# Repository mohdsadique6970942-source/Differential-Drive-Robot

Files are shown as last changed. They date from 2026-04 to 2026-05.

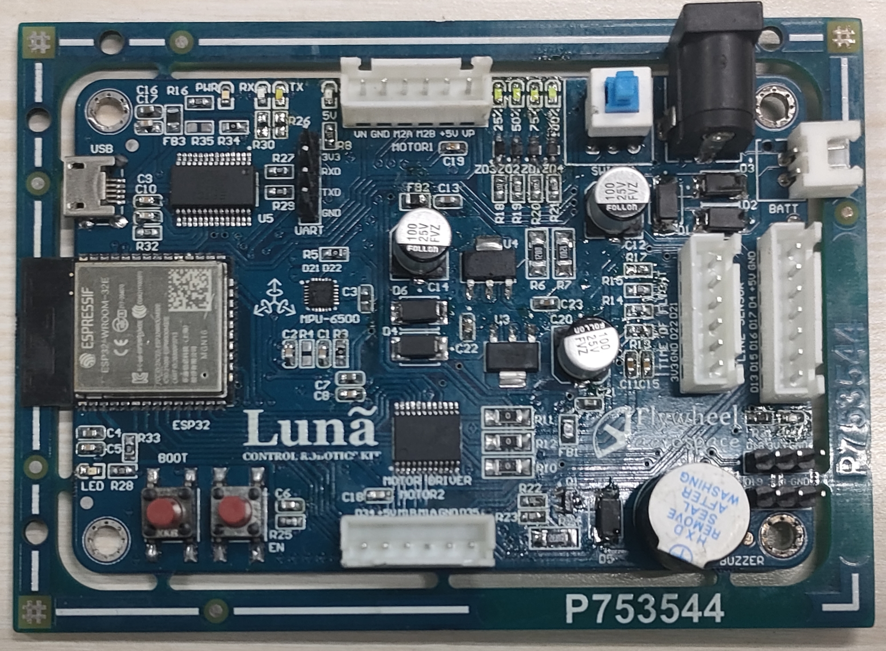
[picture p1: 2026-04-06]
PCB Design/Differrencial Drive Robot PCB Image.jpeg

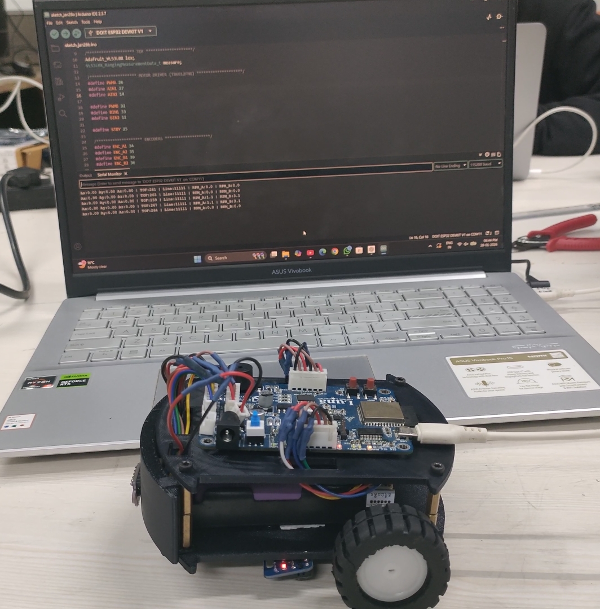
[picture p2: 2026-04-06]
Robot Images/Robot Side.jpeg

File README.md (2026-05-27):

# Differential-Drive-Robot
Differential drive mobile robot using ESP32 Dev Kit with IMU 6500, ToF, and encoder motors for precise localization, obstacle detection, and motion control. Implements sensor fusion and PID/non-PID control for accurate path tracking, also desighn a PCB for this Project with IMU, motor driver, battery charging circuit integrated in PCB, with ongoing work on mathematical modeling of the robot & development of GUI for GUI-based visualization and can get data in .csv format through GUI.

---

## 🧰 Hardware Components
- ESP32  
- IMU Sensor (MPU6500)  
- ToF Sensor (VL53L0X)  
- Two N20 DC Encoder Motors 
- Motor Driver (TB6612FNG)  
- Battery Pack (12V) 
- 3D Printed Chassis + Wheels

---

## 🔌 Pin Connections

### 🔹 Motor Driver (TB6612 / L298N Equivalent)

| Function | ESP32 Pin |
|---|---|
| PWMA (Left PWM) | 26 |
| AIN1 | 14 |
| AIN2 | 27 |
| PWMB (Right PWM) | 32 |
| BIN1 | 33 |
| BIN2 | 12 |
| STBY | 25 |

---

### 🔹 Encoder Connections

| Encoder Signal | ESP32 Pin |
|---|---|
| Left Encoder A | 34 |
| Left Encoder B | 35 |
| Right Encoder A | 39 |
| Right Encoder B | 36 |

---

### 🔹 Line Sensors (5 Array)

| Sensor | ESP32 Pin |
|---|---|
| LS1 | 4 |
| LS2 | 17 |
| LS3 | 16 |
| LS4 | 15 |
| LS5 | 13 |

---

### 🔹 IMU (MPU6050 - I2C)

| Pin | ESP32 |
|-----|---|
| VCC | 3.3V |
| GND | GND |
| SDA | 21 |
| SCL | 22 |

📌 Install Library:
- `Madgwick` (from Arduino Library Manager)

---

### 🔹 ToF Sensor (VL53L0X - I2C)

| Pin | ESP32 |
|-----|---|
| VCC | 3.3V |
| GND | GND |
| SDA | 21 |
| SCL | 22 |

📌 Install Library:
- `Adafruit_VL53L0X`

---

### 🔹 Serial Communication

| Function | Value |
|---|---|
| Baud Rate | 115200 |
| Interface | USB |

---

## 📁 Code Availability

- Individual sensor codes are available  
- Combined full system code is available
- All paths code are available 
- All codes are inside the `Robot codes` folder  
- Path execution:
  - Straight line (PID + Non-PID with jerk control)  
  - Square path (PID + Non-PID)  
  - Circular path (PID + Non-PID)
 
---

## 🖨️ 3D Print & PCB Design

- 3D printed chassis files are available in "3D print" folder
- PCB design is available in "PCB design" folder
  
---

## 🎯 Applications
- Autonomous mobile robots  
- SLAM & localization research  
- Robotics competitions  
- Smart navigation systems  

---

## 📚 Learning Outcomes
- Sensor fusion (IMU + ToF + Encoder)  
- Embedded control systems  
- PID tuning and motion control  
- Real-time robotics programming
- Mathematical Modelling

---

## 📄 License
Open-source for educational and research purposes.

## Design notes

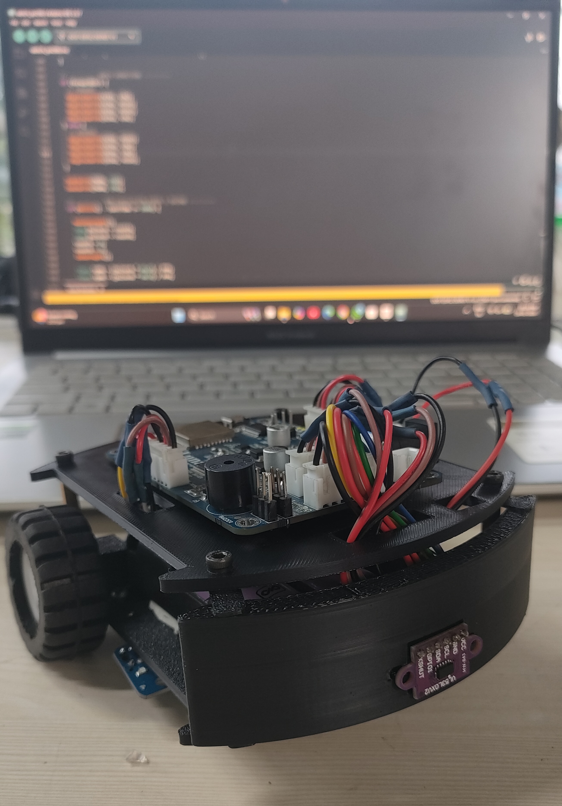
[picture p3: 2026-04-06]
Robot Images/Robot Top.jpeg

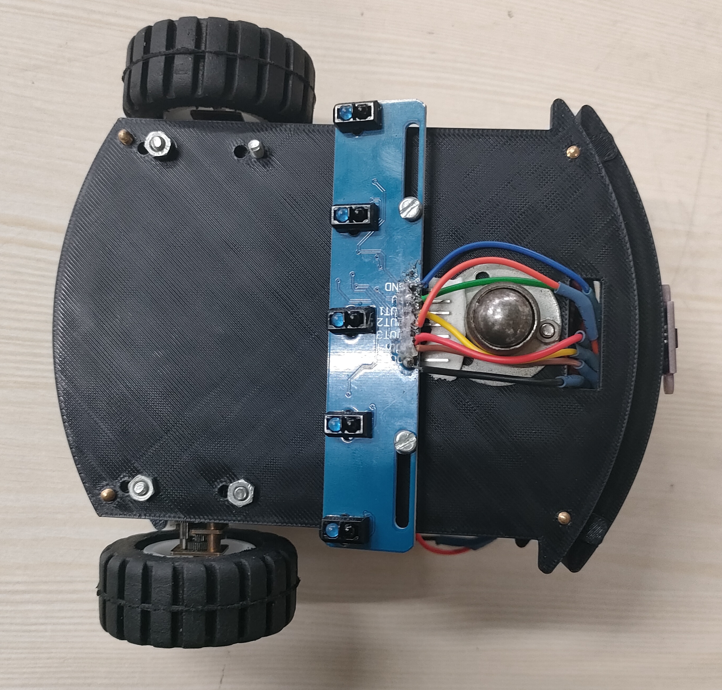
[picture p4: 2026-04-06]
Robot Images/Robot Base.jpeg

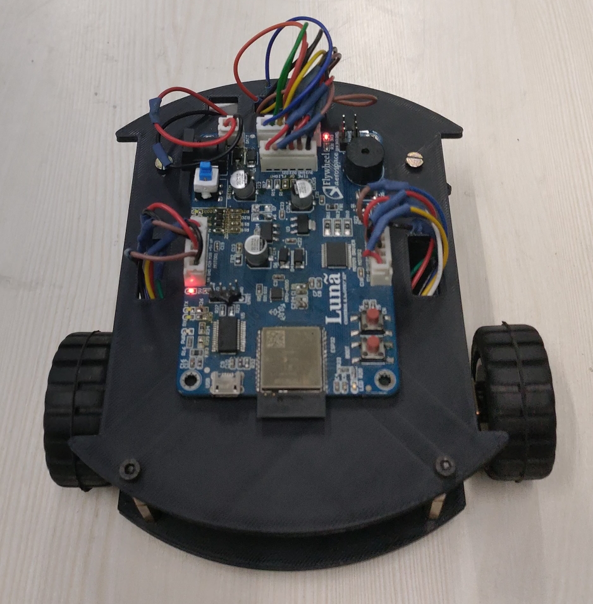
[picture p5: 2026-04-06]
Robot Images/Robot Back Top.jpeg

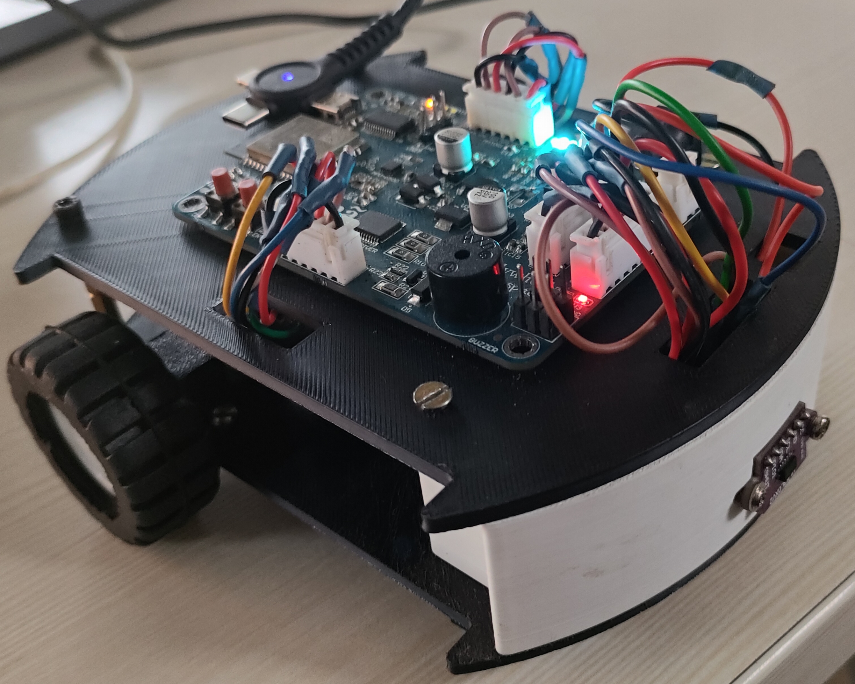
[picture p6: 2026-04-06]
Robot Images/Robot Side Top.jpeg

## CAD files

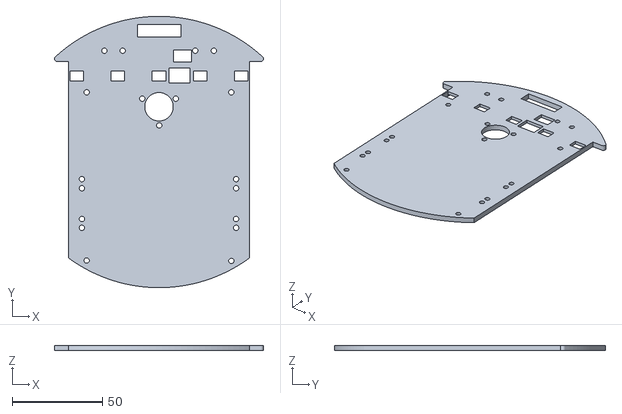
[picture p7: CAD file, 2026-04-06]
3D Prints/Robot_Base.stl
115.6 x 150.0 x 3.00

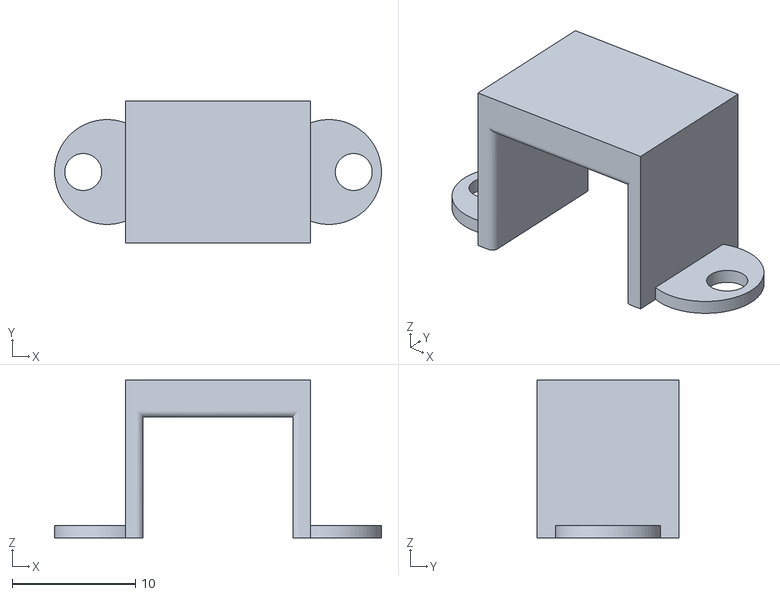
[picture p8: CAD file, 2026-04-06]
3D Prints/Robot_Motors_Clamp.stl
26.5 x 11.5 x 12.8

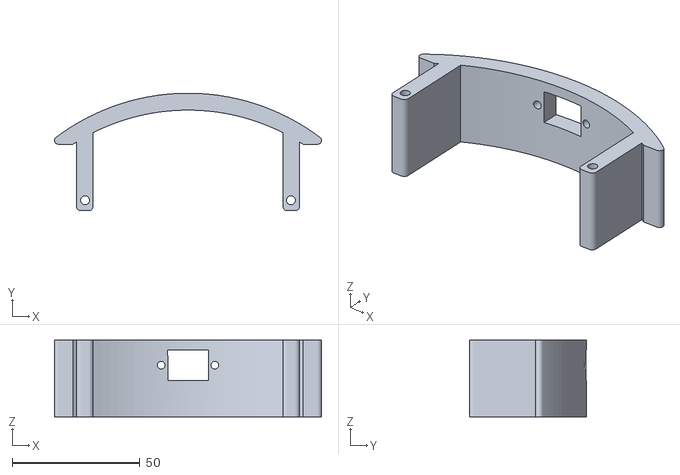
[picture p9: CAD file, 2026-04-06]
3D Prints/Robot_Front.stl
104.4 x 45.9 x 30.0

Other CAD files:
3D Prints/Robot_Top.stl

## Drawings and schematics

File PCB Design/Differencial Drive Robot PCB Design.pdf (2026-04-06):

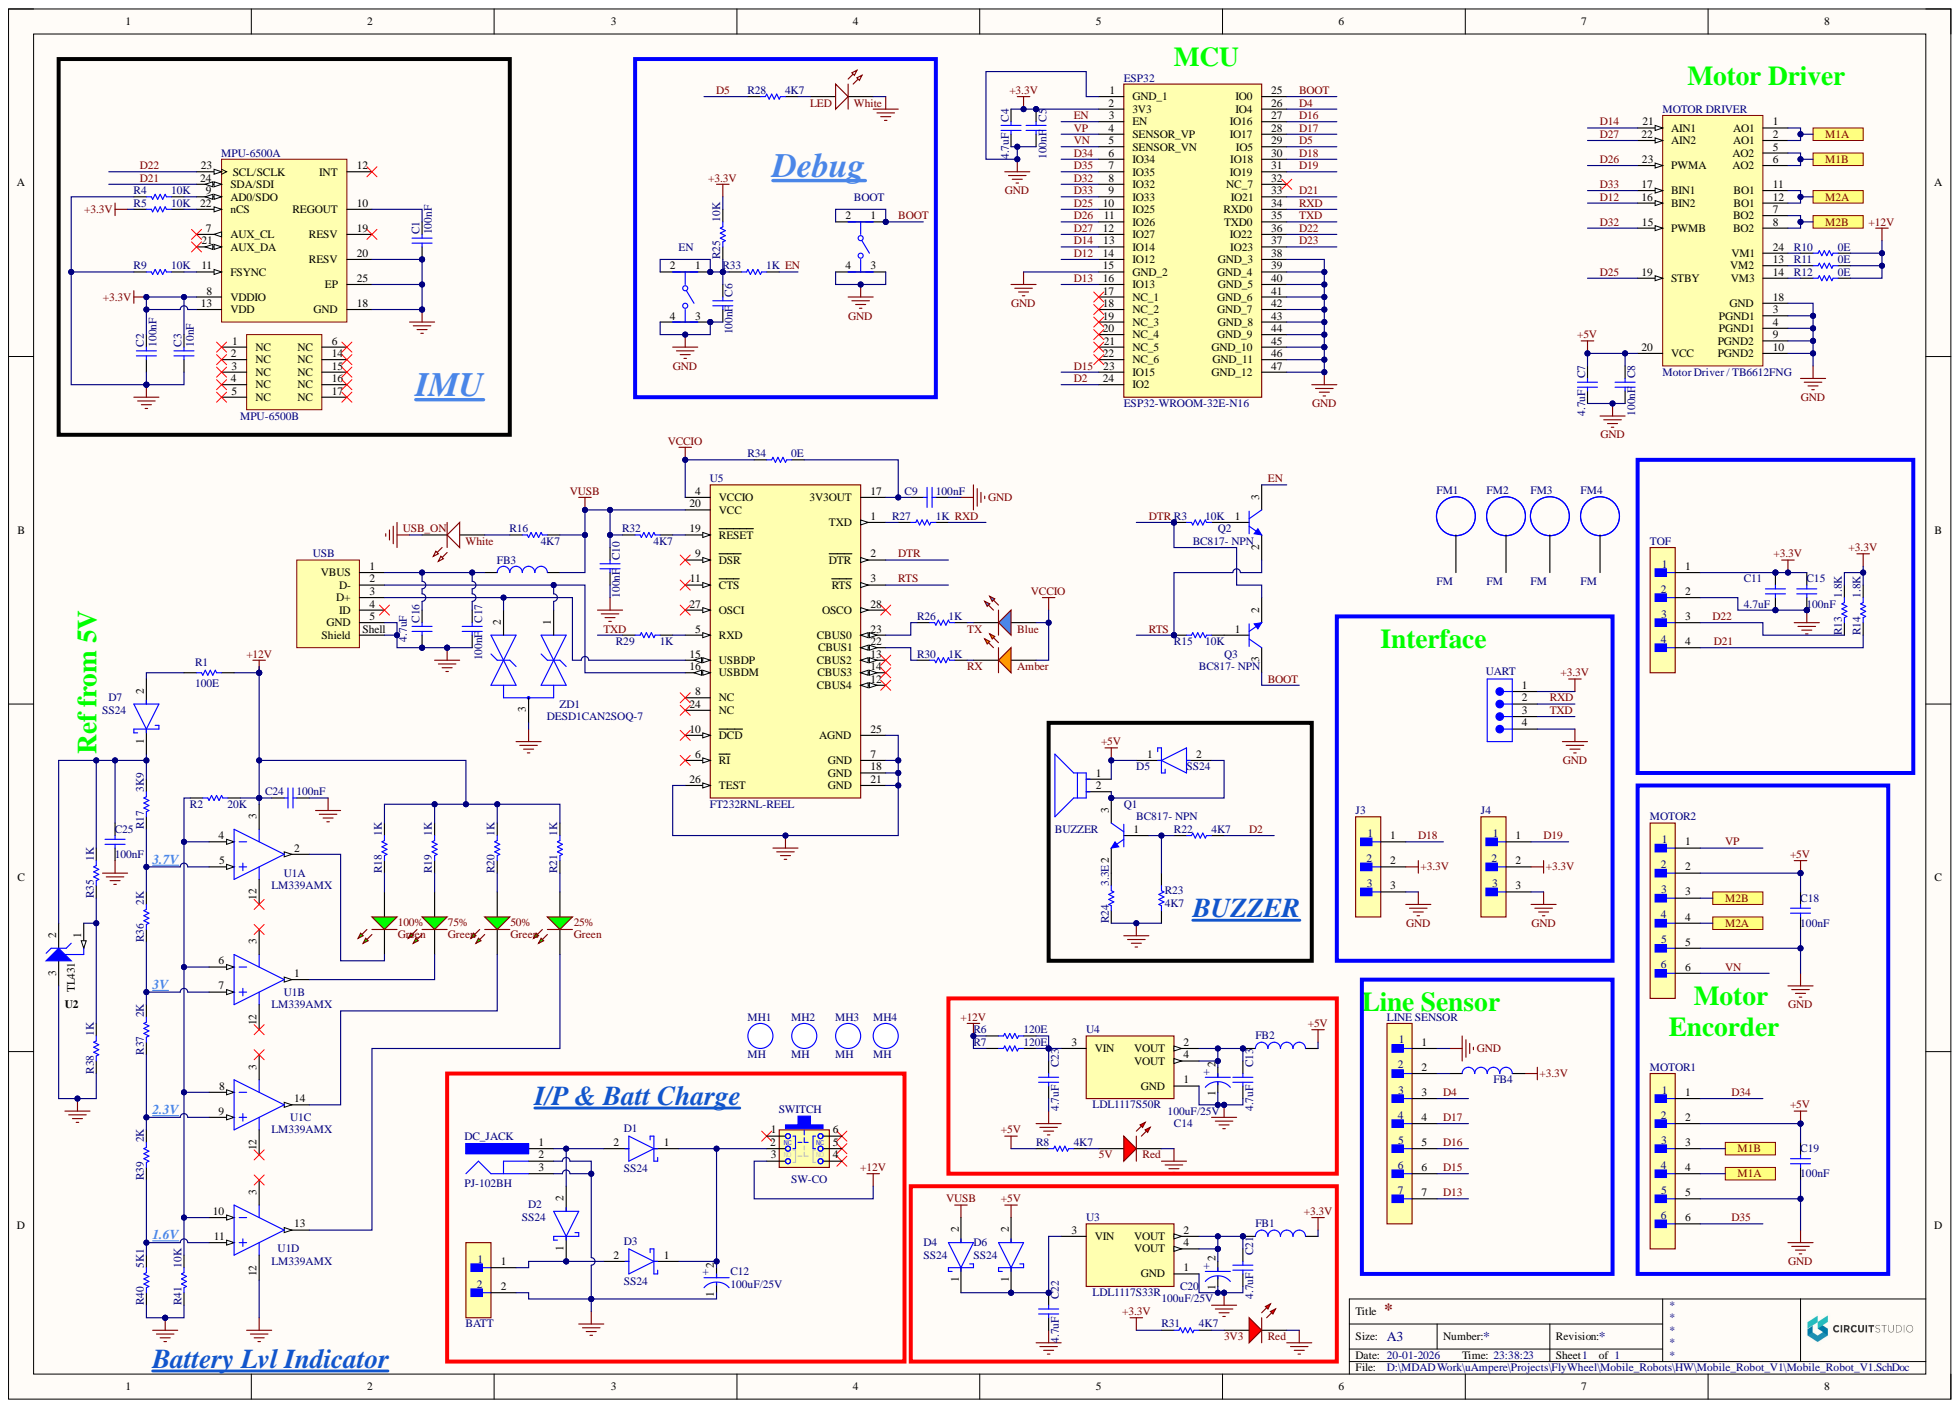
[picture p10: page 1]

VCC 20 VCCIO 4

R32 | RESET 19

D:\MDADWork\uAmpere\Projects\FlyWheel\Mobile_Robots\HW\Mobile_Robot_V1\Mobile_Robot_V1.SchDoc

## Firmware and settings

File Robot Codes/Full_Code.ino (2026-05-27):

#include <Arduino.h>
#include <Wire.h>
#include <Adafruit_VL53L0X.h>

// ── Motor pins ────────────────────────────────────────────────────────────────
#define PWMA  26
#define AIN1  27
#define AIN2  14
#define PWMB  32
#define BIN1  33
#define BIN2  12
#define STBY  25

#define PWM_FREQ   20000
#define PWM_RES    8
#define CRUISE_PWM 144

// ── Encoder pins ──────────────────────────────────────────────────────────────
#define ENC_A1  34
#define ENC_A2  35
#define ENC_B1  39
#define ENC_B2  36

// ── Line sensor pins ──────────────────────────────────────────────────────────
#define LS1  4
#define LS2  17
#define LS3  16
#define LS4  15
#define LS5  13

// ── IMU ───────────────────────────────────────────────────────────────────────
#define MPU_ADDR       0x68
#define ACCEL_SCALE    16384.0f
#define GYRO_SCALE     131.0f
#define CALIB_SAMPLES  3000
#define CALIB_DELAY_MS 2
#define ALPHA          0.96f
#define GYRO_DEADBAND  0.5f

// ── Encoder calibration ───────────────────────────────────────────────────────
#define MM_PER_TICK_A   0.049773f
#define MM_PER_TICK_B   0.050400f
#define WHEEL_CIRCUM_MM 138.230f

// ── Safety thresholds ─────────────────────────────────────────────────────────
#define TOF_STOP_MM        300    // stop if object within 30 cm
#define CLIFF_SIGNAL       LOW    // sensor reads LOW over cliff
#define CLIFF_THRESHOLD    3      // min sensors to confirm cliff
#define TOF_INTERVAL_MS    50
#define PRINT_INTERVAL_MS  100

// ── Encoder state ─────────────────────────────────────────────────────────────
volatile long countA = 0;
volatile long countB = 0;
volatile int  lastA  = 0;
volatile int  lastB  = 0;

// ── IMU state ─────────────────────────────────────────────────────────────────
float accX, accY, accZ;
float gyroX, gyroY, gyroZ;
float accX_off=0, accY_off=0, accZ_off=0;
float gyroX_off=0, gyroY_off=0, gyroZ_off=0;
float roll=0, pitch=0, yaw=0;
unsigned long imuPrevTime;
float imuDt;

// ── ToF ───────────────────────────────────────────────────────────────────────
Adafruit_VL53L0X lox;
uint16_t tofDistance  = 9999;
uint16_t tofStart     = 0;
unsigned long lastTofRead = 0;

// ── Speed tracking ────────────────────────────────────────────────────────────
unsigned long speedPrevTime = 0;
long          speedPrevA    = 0;
long          speedPrevB    = 0;

// ── Robot state ───────────────────────────────────────────────────────────────
bool robotRunning  = false;
bool stoppedByTof  = false;
bool stoppedByCliff= false;
float cliffDistMm  = 0;

unsigned long lastPrint = 0;

// ─────────────────────────────────────────────────────────────────────────────
//  ISRs
// ─────────────────────────────────────────────────────────────────────────────
void IRAM_ATTR encoderA_ISR() {
  int a = digitalRead(ENC_A1);
  int b = digitalRead(ENC_A2);
  int encoded = (a << 1) | b;
  int sum = (lastA << 2) | encoded;
  if (sum == 13 || sum == 4 || sum == 2 || sum == 11) countA++;
  if (sum == 14 || sum == 7 || sum == 1 || sum == 8)  countA--;
  lastA = encoded;
}

void IRAM_ATTR encoderB_ISR() {
  int a = digitalRead(ENC_B1);
  int b = digitalRead(ENC_B2);
  int encoded = (a << 1) | b;
  int sum = (lastB << 2) | encoded;
  if (sum == 13 || sum == 4 || sum == 2 || sum == 11) countB++;
  if (sum == 14 || sum == 7 || sum == 1 || sum == 8)  countB--;
  lastB = encoded;
}

// ─────────────────────────────────────────────────────────────────────────────
//  Motor control
// ─────────────────────────────────────────────────────────────────────────────
void motorsForward(int pwm) {
  digitalWrite(AIN1, HIGH); digitalWrite(AIN2, LOW);
  digitalWrite(BIN1, HIGH); digitalWrite(BIN2, LOW);
  ledcWrite(PWMA, pwm);
  ledcWrite(PWMB, pwm);
}

void motorsStop() {
  ledcWrite(PWMA, 0);
  ledcWrite(PWMB, 0);
}

// ─────────────────────────────────────────────────────────────────────────────
//  Encoder helpers
// ─────────────────────────────────────────────────────────────────────────────
void resetEncoders() {
  noInterrupts();
  countA = 0; countB = 0;
  interrupts();
  speedPrevA = 0; speedPrevB = 0;
}

float encA_mm() { noInterrupts(); long s=countA; interrupts(); return s*MM_PER_TICK_A; }
float encB_mm() { noInterrupts(); long s=countB; interrupts(); return s*MM_PER_TICK_B; }
float botDist_mm() { return (encA_mm() + encB_mm()) / 2.0f; }

// ─────────────────────────────────────────────────────────────────────────────
//  Line sensor helpers
// ─────────────────────────────────────────────────────────────────────────────
int cliffCount() {
  return (digitalRead(LS1)==CLIFF_SIGNAL) +
         (digitalRead(LS2)==CLIFF_SIGNAL) +
         (digitalRead(LS3)==CLIFF_SIGNAL) +
         (digitalRead(LS4)==CLIFF_SIGNAL) +
         (digitalRead(LS5)==CLIFF_SIGNAL);
}

const char* cliffSide() {
  bool l  = (digitalRead(LS1)==CLIFF_SIGNAL);
  bool ml = (digitalRead(LS2)==CLIFF_SIGNAL);
  bool c  = (digitalRead(LS3)==CLIFF_SIGNAL);
  bool mr = (digitalRead(LS4)==CLIFF_SIGNAL);
  bool r  = (digitalRead(LS5)==CLIFF_SIGNAL);
  int  n  = l+ml+c+mr+r;
  if (n >= 4)          return "FULL";
  if (l  && ml && !r)  return "LEFT";
  if (r  && mr && !l)  return "RIGHT";
  if (c  && !l && !r)  return "CENTER";
  if (l  && !r)        return "FRONT-LEFT";
  if (r  && !l)        return "FRONT-RIGHT";
  return "PARTIAL";
}

// ─────────────────────────────────────────────────────────────────────────────
//  IMU
// ─────────────────────────────────────────────────────────────────────────────
void initMPU() {
  Wire.beginTransmission(MPU_ADDR);
  Wire.write(0x6B); Wire.write(0x01);
  Wire.endTransmission(true);
  delay(100);

  Wire.beginTransmission(MPU_ADDR);
  Wire.write(0x1A); Wire.write(0x03);
  Wire.endTransmission(true);

  Wire.beginTransmission(MPU_ADDR);
  Wire.write(0x1B); Wire.write(0x00);
  Wire.endTransmission(true);

  Wire.beginTransmission(MPU_ADDR);
  Wire.write(0x1C); Wire.write(0x00);
  Wire.endTransmission(true);
  delay(200);
}

void readMPU() {
  Wire.beginTransmission(MPU_ADDR);
  Wire.write(0x3B);
  Wire.endTransmission(false);
  Wire.requestFrom((uint8_t)MPU_ADDR, (uint8_t)14, (uint8_t)true);

  accX  = (int16_t)(Wire.read()<<8 | Wire.read()) / ACCEL_SCALE;
  accY  = (int16_t)(Wire.read()<<8 | Wire.read()) / ACCEL_SCALE;
  accZ  = (int16_t)(Wire.read()<<8 | Wire.read()) / ACCEL_SCALE;
  Wire.read(); Wire.read();
  gyroX = (int16_t)(Wire.read()<<8 | Wire.read()) / GYRO_SCALE;
  gyroY = (int16_t)(Wire.read()<<8 | Wire.read()) / GYRO_SCALE;
  gyroZ = (int16_t)(Wire.read()<<8 | Wire.read()) / GYRO_SCALE;
}

void applyOffsets() {
  accX -= accX_off; accY -= accY_off; accZ -= accZ_off;
  gyroX -= gyroX_off; gyroY -= gyroY_off; gyroZ -= gyroZ_off;
}

void calibrateIMU() {
  Serial.println("Calibrating IMU... DO NOT MOVE!");
  float sAX=0,sAY=0,sAZ=0,sGX=0,sGY=0,sGZ=0;
  for (int i=0; i<CALIB_SAMPLES; i++) {
    readMPU();
    sAX+=accX; sAY+=accY; sAZ+=accZ;
    sGX+=gyroX; sGY+=gyroY; sGZ+=gyroZ;
    delay(CALIB_DELAY_MS);
    if (i%500==0) Serial.print(".");
  }
  Serial.println();
  accX_off  = sAX/CALIB_SAMPLES;
  accY_off  = sAY/CALIB_SAMPLES;
  accZ_off  = (sAZ/CALIB_SAMPLES)-1.0f;
  gyroX_off = sGX/CALIB_SAMPLES;
  gyroY_off = sGY/CALIB_SAMPLES;
  gyroZ_off = sGZ/CALIB_SAMPLES;
  Serial.println("IMU calibration done!");
  Serial.printf("  Acc  offsets: X=%.4f Y=%.4f Z=%.4f\n", accX_off,  accY_off,  accZ_off);
  Serial.printf("  Gyro offsets: X=%.4f Y=%.4f Z=%.4f\n", gyroX_off, gyroY_off, gyroZ_off);
}

void updateIMU() {
  unsigned long nowUs = micros();
  imuDt = (nowUs - imuPrevTime) * 1e-6f;
  imuPrevTime = nowUs;
  if (imuDt <= 0.0f || imuDt > 0.5f) imuDt = 0.005f;

  readMPU();
  applyOffsets();

  float accRoll  = atan2f(accY, accZ) * RAD_TO_DEG;
  float accPitch = atan2f(-accX, sqrtf(accY*accY + accZ*accZ)) * RAD_TO_DEG;

  roll  = ALPHA*(roll  + gyroX*imuDt) + (1.0f-ALPHA)*accRoll;
  pitch = ALPHA*(pitch + gyroY*imuDt) + (1.0f-ALPHA)*accPitch;

  float gz = (fabsf(gyroZ) < GYRO_DEADBAND) ? 0.0f : gyroZ;
  yaw += gz * imuDt;

  // wrap yaw to 0-360
  yaw = fmodf(yaw, 360.0f);
  if (yaw < 0) yaw += 360.0f;
}

float wrapTo360(float a) {
  a = fmodf(a, 360.0f);
  if (a < 0) a += 360.0f;
  return a;
}

// ─────────────────────────────────────────────────────────────────────────────
//  Print header
// ─────────────────────────────────────────────────────────────────────────────
void printHeader() {
  Serial.println();
  Serial.println(" Roll(°) Pitch(°)  Yaw(°) | ToF(mm) | EncA(mm) EncB(mm) Bot(mm) | SpdA(mm/s) SpdB(mm/s) BotSpd(mm/s) | Sensors | State");
  Serial.println("-------------------------------------------------------------------------------------------------------------------------------");
}

// ─────────────────────────────────────────────────────────────────────────────
//  Setup
// ─────────────────────────────────────────────────────────────────────────────
void setup() {
  Serial.begin(115200);
  while (!Serial) delay(10);

  Wire.begin(21, 22);
  Wire.setClock(400000);

  // Motors
  pinMode(AIN1, OUTPUT); pinMode(AIN2, OUTPUT);
  pinMode(BIN1, OUTPUT); pinMode(BIN2, OUTPUT);
  pinMode(STBY, OUTPUT);
  digitalWrite(STBY, HIGH);
  ledcAttach(PWMA, PWM_FREQ, PWM_RES);
  ledcAttach(PWMB, PWM_FREQ, PWM_RES);
  motorsStop();

  // Encoders
  pinMode(ENC_A1, INPUT); pinMode(ENC_A2, INPUT);
  pinMode(ENC_B1, INPUT); pinMode(ENC_B2, INPUT);
  attachInterrupt(digitalPinToInterrupt(ENC_A1), encoderA_ISR, CHANGE);
  attachInterrupt(digitalPinToInterrupt(ENC_A2), encoderA_ISR, CHANGE);
  attachInterrupt(digitalPinToInterrupt(ENC_B1), encoderB_ISR, CHANGE);
  attachInterrupt(digitalPinToInterrupt(ENC_B2), encoderB_ISR, CHANGE);

  // Line sensors
  pinMode(LS1,INPUT); pinMode(LS2,INPUT); pinMode(LS3,INPUT);
  pinMode(LS4,INPUT); pinMode(LS5,INPUT);

  // ToF
  if (!lox.begin()) {
    Serial.println("ERR: VL53L0X not found!");
    while (1);
  }

  // IMU
  initMPU();
  Serial.println("Place robot FLAT and STILL for IMU calibration...");
  delay(2000);
  calibrateIMU();

  // Snapshot ToF at start
  delay(100);
  VL53L0X_RangingMeasurementData_t m;
  lox.rangingTest(&m, false);
  tofStart    = (m.RangeStatus != 4) ? m.RangeMilliMeter : 9999;
  tofDistance = tofStart;

  resetEncoders();
  speedPrevTime = millis();
  imuPrevTime   = micros();

  Serial.println("========================================");
  Serial.println("  FULL SENSOR DRIVE SYSTEM");
  Serial.printf ("  ToF stop      : %d mm\n", TOF_STOP_MM);
  Serial.printf ("  Cliff trigger : %d / 5 sensors\n", CLIFF_THRESHOLD);
  Serial.printf ("  Cruise PWM    : %d / 255\n", CRUISE_PWM);
  Serial.printf ("  ToF at start  : %d mm\n", tofStart);
  Serial.println("========================================");

  robotRunning = true;
  motorsForward(CRUISE_PWM);
  printHeader();
}

// ─────────────────────────────────────────────────────────────────────────────
//  Loop
// ─────────────────────────────────────────────────────────────────────────────
void loop() {
  unsigned long now = millis();

  // ── IMU — update every loop ───────────────────────────────────────────────
  updateIMU();

  // ── ToF — every 50 ms ─────────────────────────────────────────────────────
  if (now - lastTofRead >= TOF_INTERVAL_MS) {
    lastTofRead = now;
    VL53L0X_RangingMeasurementData_t measure;
    lox.rangingTest(&measure, false);
    if (measure.RangeStatus != 4) tofDistance = measure.RangeMilliMeter;

    if (robotRunning && tofDistance <= TOF_STOP_MM) {
      robotRunning = false;
      stoppedByTof = true;
      motorsStop();
      Serial.printf("\n!! TOF STOP — obstacle at %d mm — Bot travelled %.2f mm\n",
                    tofDistance, botDist_mm());
      printHeader();
    }
  }

  // ── Cliff — every loop for fast response ──────────────────────────────────
  if (robotRunning) {
    int cc = cliffCount();
    if (cc >= CLIFF_THRESHOLD) {
      robotRunning   = false;
      stoppedByCliff = true;
      cliffDistMm    = botDist_mm();
      motorsStop();
      Serial.printf("\n!! CLIFF STOP — side: %s — %d/5 sensors — at %.2f mm\n",
                    cliffSide(), cc, cliffDistMm);
      printHeader();
    }
  }

  // ── Print — every 100 ms ──────────────────────────────────────────────────
  if (now - lastPrint >= PRINT_INTERVAL_MS) {
    lastPrint = now;

    // Encoder distances
    noInterrupts();
    long sA = countA;
    long sB = countB;
    interrupts();
    float mmA = sA * MM_PER_TICK_A;
    float mmB = sB * MM_PER_TICK_B;
    float avg = (mmA + mmB) / 2.0f;

    // Wheel speeds
    float dt  = (now - speedPrevTime) / 1000.0f;
    dt = (dt < 0.001f) ? 0.001f : dt;
    float spdA   = ((sA - speedPrevA) * MM_PER_TICK_A) / dt;
    float spdB   = ((sB - speedPrevB) * MM_PER_TICK_B) / dt;
    float avgSpd = (spdA + spdB) / 2.0f;
    speedPrevA    = sA;
    speedPrevB    = sB;
    speedPrevTime = now;

    // Sensor bar  C=cliff  -=clear
    char sensors[6];
    sensors[0] = (digitalRead(LS1)==CLIFF_SIGNAL) ? 'C' : '-';
    sensors[1] = (digitalRead(LS2)==CLIFF_SIGNAL) ? 'C' : '-';
    sensors[2] = (digitalRead(LS3)==CLIFF_SIGNAL) ? 'C' : '-';
    sensors[3] = (digitalRead(LS4)==CLIFF_SIGNAL) ? 'C' : '-';
    sensors[4] = (digitalRead(LS5)==CLIFF_SIGNAL) ? 'C' : '-';
    sensors[5] = '\0';

    // State label
    const char* state = robotRunning   ? " MOVING " :
                        stoppedByTof   ? "TOF-STOP" :
                        stoppedByCliff ? "CLF-STOP" : "STOPPED ";

    Serial.printf("%7.2f  %7.2f  %6.2f | %7d | %8.2f %8.2f %7.2f | %10.2f %10.2f %11.2f | %s | %s\n",
      wrapTo360(roll),
      wrapTo360(pitch),
      yaw,
      tofDistance,
      mmA, mmB, avg,
      spdA, spdB, avgSpd,
      sensors,
      state
    );
  }

  delay(2);
}

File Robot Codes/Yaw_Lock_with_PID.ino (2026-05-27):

#include <Wire.h>

#define MPU_ADDR       0x68
#define ACCEL_SCALE    16384.0f
#define GYRO_SCALE     131.0f
#define CALIB_SAMPLES  3000
#define CALIB_DELAY_MS 2
#define ALPHA          0.96f
#define GYRO_DEADBAND  0.5f

#define PWMA 26
#define AIN1 27
#define AIN2 14

#define PWMB 32
#define BIN1 33
#define BIN2 12

#define ENC1_A 34
#define ENC1_B 35
#define ENC2_A 36
#define ENC2_B 39

#define STBY 25

#define KP            5.0f   
#define KI            0.08f  
#define KD            2.0f   
#define INTEGRAL_LIMIT 30.0f 
#define MAX_SPEED      150   
#define MIN_SPEED      55    
#define DEAD_ZONE      0.5f  

float accX, accY, accZ;
float gyroX, gyroY, gyroZ;

float accX_off=0, accY_off=0, accZ_off=0;
float gyroX_off=0, gyroY_off=0, gyroZ_off=0;

float roll=0, pitch=0, yaw=0;
float accRoll, accPitch;

unsigned long prevTime;
float dt;

float targetYaw   = 0;
float integral    = 0;
float prevError   = 0;

volatile long leftEncoderCount  = 0;
volatile long rightEncoderCount = 0;

// ✅ FIXED ISR (direction based on motor command)
void IRAM_ATTR leftEncoderISR() {
  if (digitalRead(AIN1) == HIGH && digitalRead(AIN2) == LOW)
    leftEncoderCount++;
  else
    leftEncoderCount--;
}

void IRAM_ATTR rightEncoderISR() {
  if (digitalRead(BIN1) == HIGH && digitalRead(BIN2) == LOW)
    rightEncoderCount++;
  else
    rightEncoderCount--;
}

void initMPU();
void calibrateAll();
void readMPU();
void applyOffsets();
float wrapTo180(float angle);
void updateIMU();
void setMotor(int left, int right);

void setup() {
  Serial.begin(115200);

  pinMode(AIN1, OUTPUT);
  pinMode(AIN2, OUTPUT);
  pinMode(BIN1, OUTPUT);
  pinMode(BIN2, OUTPUT);
  pinMode(STBY, OUTPUT);
  digitalWrite(STBY, HIGH);

  ledcAttach(PWMA, 20000, 8);
  ledcAttach(PWMB, 20000, 8);

  pinMode(ENC1_A, INPUT_PULLUP);
  pinMode(ENC2_A, INPUT_PULLUP);

  attachInterrupt(digitalPinToInterrupt(ENC1_A), leftEncoderISR,  RISING);
  attachInterrupt(digitalPinToInterrupt(ENC2_A), rightEncoderISR, RISING);

  Wire.begin(21, 22);
  Wire.setClock(400000);
  initMPU();

  delay(2000);
  calibrateAll();

  leftEncoderCount  = 0;
  rightEncoderCount = 0;

  prevTime = micros();
  updateIMU();

  targetYaw = yaw;
}

void loop() {

  updateIMU();

  float error = wrapTo180(targetYaw - yaw);

  if (fabsf(error) < DEAD_ZONE) {
    setMotor(0, 0);
    integral  = 0;
    prevError = 0;
  } else {
    integral += error * dt;
    integral  = constrain(integral, -INTEGRAL_LIMIT, INTEGRAL_LIMIT);

    float derivative = 0;
    if (dt > 0.0005f) {
      derivative = (error - prevError) / dt;
    }
    prevError = error;

    float output = (KP * error) + (KI * integral) + (KD * derivative);

    int speed = (int)fabsf(output);
    speed = constrain(speed, MIN_SPEED, MAX_SPEED);

    if (output > 0) {
      setMotor( speed, -speed);   
    } else {
      setMotor(-speed,  speed);   
    }
  }

  noInterrupts();
  long leftCount  = leftEncoderCount;
  long rightCount = rightEncoderCount;
  interrupts();

  Serial.print(millis() / 1000.0, 3);
  Serial.print(",");
  Serial.print(yaw, 2);
  Serial.print(",");
  Serial.print(leftCount);
  Serial.print(",");
  Serial.println(rightCount);

  delay(10);
}

void setMotor(int left, int right) {
  if (left >= 0) { digitalWrite(AIN1, HIGH); digitalWrite(AIN2, LOW);  }
  else           { digitalWrite(AIN1, LOW);  digitalWrite(AIN2, HIGH); left  = -left;  }

  if (right >= 0) { digitalWrite(BIN1, HIGH); digitalWrite(BIN2, LOW);  }
  else            { digitalWrite(BIN1, LOW);  digitalWrite(BIN2, HIGH); right = -right; }

  ledcWrite(PWMA, left);
  ledcWrite(PWMB, right);
}

void updateIMU() {
  unsigned long now = micros();
  dt = (now - prevTime) * 1e-6f;
  prevTime = now;

  if (dt <= 0.0f || dt > 0.5f) dt = 0.005f;

  readMPU();
  applyOffsets();

  accRoll  = atan2f(accY, accZ) * RAD_TO_DEG;
  accPitch = atan2f(-accX, sqrtf(accY*accY + accZ*accZ)) * RAD_TO_DEG;

  roll  = ALPHA * (roll  + gyroX * dt) + (1 - ALPHA) * accRoll;
  pitch = ALPHA * (pitch + gyroY * dt) + (1 - ALPHA) * accPitch;

  float gz = gyroZ;
  if (fabsf(gz) < GYRO_DEADBAND) gz = 0;

  yaw += gz * dt;
  yaw  = wrapTo180(yaw);
}

void initMPU() {
  Wire.beginTransmission(MPU_ADDR); Wire.write(0x6B); Wire.write(0x01); Wire.endTransmission(true);
  delay(100);
  Wire.beginTransmission(MPU_ADDR); Wire.write(0x1A); Wire.write(0x03); Wire.endTransmission(true);
  Wire.beginTransmission(MPU_ADDR); Wire.write(0x1B); Wire.write(0x00); Wire.endTransmission(true);
  Wire.beginTransmission(MPU_ADDR); Wire.write(0x1C); Wire.write(0x00); Wire.endTransmission(true);
  delay(200);
}

void calibrateAll() {
  float sAX=0, sAY=0, sAZ=0;
  float sGX=0, sGY=0, sGZ=0;

  for (int i = 0; i < CALIB_SAMPLES; i++) {
    readMPU();
    sAX += accX; sAY += accY; sAZ += accZ;
    sGX += gyroX; sGY += gyroY; sGZ += gyroZ;
    delay(CALIB_DELAY_MS);
  }

  accX_off = sAX / CALIB_SAMPLES;
  accY_off = sAY / CALIB_SAMPLES;
  accZ_off = (sAZ / CALIB_SAMPLES) - 1.0f;

  gyroX_off = sGX / CALIB_SAMPLES;
  gyroY_off = sGY / CALIB_SAMPLES;
  gyroZ_off = sGZ / CALIB_SAMPLES;
}

void readMPU() {
  Wire.beginTransmission(MPU_ADDR);
  Wire.write(0x3B);
  Wire.endTransmission(false);
  Wire.requestFrom((uint8_t)MPU_ADDR, (uint8_t)14, (uint8_t)true);

  accX = (int16_t)(Wire.read()<<8 | Wire.read()) / ACCEL_SCALE;
  accY = (int16_t)(Wire.read()<<8 | Wire.read()) / ACCEL_SCALE;
  accZ = (int16_t)(Wire.read()<<8 | Wire.read()) / ACCEL_SCALE;

  Wire.read(); Wire.read();

  gyroX = (int16_t)(Wire.read()<<8 | Wire.read()) / GYRO_SCALE;
  gyroY = (int16_t)(Wire.read()<<8 | Wire.read()) / GYRO_SCALE;
  gyroZ = (int16_t)(Wire.read()<<8 | Wire.read()) / GYRO_SCALE;
}

void applyOffsets() {
  accX -= accX_off; accY -= accY_off; accZ -= accZ_off;
  gyroX -= gyroX_off; gyroY -= gyroY_off; gyroZ -= gyroZ_off;
}

float wrapTo180(float angle) {
  angle = fmodf(angle + 180.0f, 360.0f);
  if (angle < 0) angle += 360.0f;
  return angle - 180.0f;
}
